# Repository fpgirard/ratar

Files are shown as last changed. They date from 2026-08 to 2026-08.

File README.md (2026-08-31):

Ratar logo

# Ratar

*Rage Against the Alkaline Remote — RF signal capture & replay with an XIAO ESP32-C6 and CC1101*

<br clear="left"/>

Just as [Paul Wieland built his Ratgdo](https://www.nytimes.com/2025/12/04/technology/personaltech/why-on),
my goal was equally simple: an open-source, sub-$10 device to control my Minka-Aire
fans (FCC ID **KUJCE10007**), built from the same kind of open-source
software and commodity parts he used — ESPHome, 3D printing, inexpensive
ESP32 boards with an added CC1101-based RF module.

I also planned to capture my Minka-Aire remotes' RF codes directly, or fall
back to a [Flipper repository of RF codes](https://github.com/search?q=repo%3AZero-Sploit%2FFlipperZero-Subghz-DB+minka&type=code)
if needed.

While Ratar is narrow in scope today, I designed it to support a much
larger idea: a universal, community-supported RF/IR transceiver, where the
hardware (PCBs), software (YAML), and CAD (OpenSCAD) files are shared and
easily extensible to any 300–928MHz remote. (I'm currently adding an IR
LED/receiver to the Ratar HAT.)

---

## Repo layout

It's clean and simple, and should be easy to navigate. Questions or
comments? Please use Issues above to post.

| Path | Contents |
|---|---|
| [`pcb/README.md`](pcb/README.md) | Hardware — component list, CC1101↔XIAO pin assignments, the RF-HAT KiCad project |
| [`src/README.md`](src/README.md) | Software — the ESPHome `cc1101` config, reverse-engineering notes, Signal Bench pointer |
| [`3d/README.md`](3d/README.md) | Enclosure — parametric OpenSCAD design for the printed case |
| `OPL_Kicad_Library/` | Git submodule — Seeed's KiCad footprint/symbol library, used by the RF-HAT PCB |
| `ratar.svg`, `ratar-color.svg` | Project logo |

`OPL_Kicad_Library/` is a git submodule, so clone with:

```sh
git clone --recurse-submodules https://github.com/fpgirard/ratar.git
```

(Already cloned without it? Run `git submodule update --init` to pull it in.)

---

## Future enhancements

See each area's own README for topic-specific roadmap items (IR support and
protocol decoding in [`src/`](src/README.md), the KiCad schematic net-label
cleanup in [`pcb/`](pcb/README.md)).

By design, the house-shaped Ratar logo is drawn from the KiCad copper
traces on the PCB HAT. :)

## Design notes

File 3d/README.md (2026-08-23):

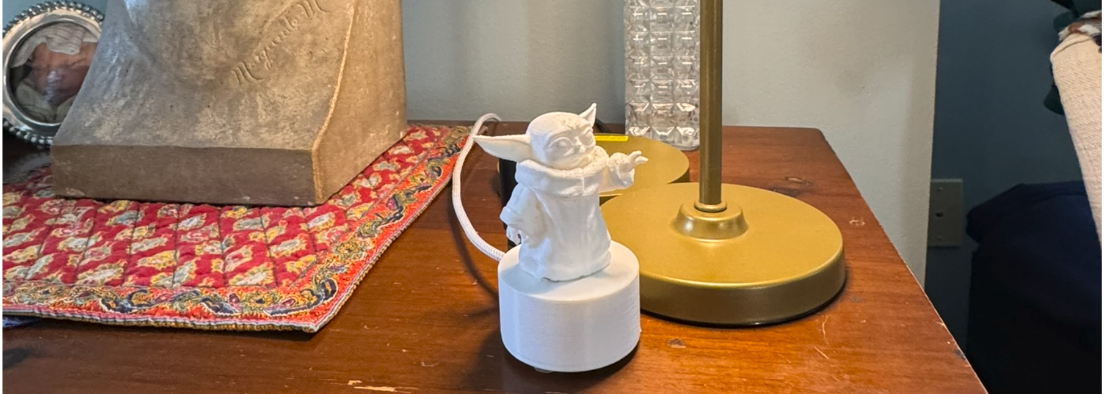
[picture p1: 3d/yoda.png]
3D-printed Grogu figurine, unrelated to Ratar -- just for fun


# Enclosure

*Ratar's printed enclosure: a parametric OpenSCAD (BOSL2) design*

A 50mm-diameter cylindrical two-part enclosure (base + lid) for the RF-HAT
board, sized to hold both the XIAO ESP32-C6 + CC1101 stack and a second,
wider board tier above it. Yoda is optional.

## Design highlights

- **Two-tier cavity**: a board cavity sized to the PCB, with a wider cutout
  starting partway up that continues through the top of the base — room for
  a second, larger board or extra component clearance above the main stack.
- **Antenna and USB-C cutouts**: both the round cable hole and the
  USB-C slot on the outer wall are cut as a small through-bore plus a wider,
  shallow counterbore pocket with a controlled flat shoulder between them —
  the trick that lets a flat connector face sit cleanly on an otherwise
  curved wall.
- **Bolted lid**: two M2 socket-head (Allen) bolts thread into heat-set
  brass inserts in the body, rather than a snap-fit or press-fit-only lid.
- **Fully parametric**: every dimension — board size, wall thickness, hole
  positions/sizes, bolt spacing, standoff heights — is a named variable at
  the top of the `.scad` file. Re-render after changing any of them.

## Print notes

Base and lid both print flat on the bed as oriented in the file (open
side / lid facing up); no supports needed.

## Files

- `ratar.scad` — the parametric source. Requires the
  [BOSL2](https://github.com/BelfrySCAD/BOSL2) OpenSCAD library
  (`include <BOSL2/std.scad>`, `include <BOSL2/screws.scad>`).
- `ratar.stl`.  Exported mesh, ready to slice.

To regenerate the STL after editing the source:

```sh
openscad -o ratar.stl ratar.scad
```

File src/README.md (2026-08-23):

Ratar logo

# Software

*ESPHome firmware for Ratar — RF capture and replay on the CC1101*

There are 2 software components in Ratar: 1. The ESPHome yaml configuration
file necessary to control your RF-based devices.  2. Signal Bench - a prototype
database to help the community collect and share their raw codes.  This resource
will be made available if the community requests it - while realizing that 
existing RF and IR code repositories already exist.   

## ESPHome + the built-in `cc1101` component

The build uses ESPHome's **official `cc1101` component**, added in
ESPHome **2025.12.0**. This was a major simplification partway through the
project — earlier revisions hand-rolled every SPI register write (reset
sequence, frequency registers, modulation config) either via Arduino's
`SPIClass` or, on the ESP-IDF-only C6, via raw bit-banged `gpio_set_level()`
calls. The built-in component eliminates all of that: frequency and
modulation are plain YAML keys, and it integrates directly with ESPHome's
standard `remote_receiver` / `remote_transmitter` components for capture
and replay.

## Complete working configuration

Please review the file `rf-transceiver-sample.yaml` for a working configuration.

## Why 304MHz, not 315MHz

315MHz is the common default assumption for fixed-code fan/garage remotes,
but this specific remote's FCC filing (FCC ID KUJCE10007) documents
**304.0MHz** as its actual operating frequency. Worth checking your own
device's FCC filing rather than assuming a round-number default — the
CC1101's filter bandwidth has some tolerance, but being off by 10MHz+ can
mean the difference between a clean capture and nothing at all.

## Frequency/reverse-engineering notes worth preserving

- Both remotes use a **fixed-code, non-rolling** OOK protocol: an 8-bit
  device/address prefix plus a 4-bit command suffix, with each button
  repeating its code ~6-7 times per press (~11,800µs gap between repeats).
- The two remotes have distinct address prefixes (`00000000` and
  `00000001`), confirming the address bits are what let two remotes/fans
  coexist without cross-triggering each other.
- One remote's "reverse" function was concluded to not exist via RF at
  all: applying the working remote's reverse command-suffix to the other
  remote's address prefix predicts a code that's identical to that
  remote's existing High Speed command — a genuine collision, not a
  capture failure. That fan's direction control is very likely a
  mechanical switch in the receiver canopy instead.
- Long-press behavior (dimming) on this remote family is **receiver-side**:
  holding a light button just re-sends the identical toggle code
  continuously: there's no distinct "dim" RF command. Simulating
  press-and-hold dimming in ESPHome means looping `transmit_raw` on a
  timer until told to stop, not sending a different code.

## Directory contents

- `rf-transceiver-sample.yaml` — the ESPHome CC1101 RF capture/replay
  config, with placeholder secrets and API key. Your own `rf-transceiver.yaml`
  (real device name, API key, captured codes) is gitignored — copy the
  sample to that filename and fill in your own values.
- `fix_xiao_footprints.py` — utility script for XIAO KiCad footprint fixes.

## Related: Signal Bench

**Signal Bench** is a separate, self-hosted FastAPI web app (not vendored in
this repo) built alongside this project for cataloging RF/IR codes as a
community resource — paste raw ESPHome `remote_receiver` debug output and it
parses, renders, and stores the code, seeded with the real captures from
this project. See that app's own README for setup.

## Future enhancements

- **IR transmitter and receiver support on the same board.** The CC1101
  handles sub-GHz RF; a standard IR LED (TX) and demodulating IR receiver
  module (RX, e.g. a VS1838B) would let one device handle both RF and IR
  devices in a home, using the same `remote_transmitter`/`remote_receiver`
  pattern already proven here — ESPHome's `remote_receiver`/
  `remote_transmitter` components are protocol-agnostic and already used
  for IR in most ESPHome IR-blaster builds.
- **Protocol-level decoding**, not just raw replay — recognizing known
  encodings (NEC, RC5, etc. for IR; common fixed-code and rolling-code
  families for RF) so Signal Bench can show a decoded address/command
  breakdown automatically instead of just the raw pulse train.
- **Frequency sweep / auto-detect** for captures, rather than requiring the
  operating frequency to be known ahead of time (useful for devices without
  an easily found FCC filing).
- **Moderation/verification workflow** for Signal Bench submissions, so a
  growing public catalog stays trustworthy as more contributors add codes.

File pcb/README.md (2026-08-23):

Ratar logo

# Hardware

*RF-HAT — CC1101 ↔ XIAO ESP32-C6 carrier board*

Ratar's hardware has four parts: the XIAO ESP32-C6, a CC1101 sub-GHz
transceiver module, Ratar's custom carrier PCB (the "RF-HAT"), and an SMA
antenna.

| Component | Role |
|---|---|
| **Seeed XIAO ESP32-C6** | Main microcontroller. Chosen over the ESP32-S3 specifically for its **built-in ceramic antenna** — avoids needing an external antenna for the C6's own WiFi/BLE radio. Requires the **ESP-IDF** framework in ESPHome (Arduino isn't supported on this chip). |
| **CC1101 sub-GHz transceiver module** (8-pin breakout, SMA antenna connector) | The actual RF transceiver. Handles 300–928MHz, ASK/OOK and other modulations. Controlled entirely over SPI. |
| **Custom KiCad PCB ("RF-HAT")** | Connects the CC1101 module's 8-pin header to the XIAO C6's pins — designed with copper traces in the shape of a house (see the logo), and verified against the pinout table below before fabrication. |
| **Right-angled SMA antenna** | Rated for the ~300MHz range Minka-Aire remotes use — not all "SMA-compatible" antennas are tuned correctly for this band. An elbow connector is worth using if the antenna would otherwise sit close to and in-line with a noise source like a USB-C cable/connector, since it moves the radiating element further away and off-axis. |

## Pin assignments — CC1101 ↔ XIAO ESP32-C6 (final)

| CC1101 Pin # | Signal | XIAO Pin | GPIO | Notes |
|---|---|---|---|---|
| 1 | GND | GND | - | |
| 2 | VCC | 3V3 | - | 1.8-3.6V only - never 5V |
| 3 | GDO0 | D2 | GPIO2  | Wired to `remote_transmitter` (TX path) |
| 4 | CSN | D3 | GPIO21 | SPI chip select |
| 5 | SCK | D8 | GPIO19 | SPI clock |
| 6 | MOSI | D10 | GPIO18 | SPI data in |
| 7 | MISO / GDO1 | D9 | GPIO20 | SPI data out (dual-purpose pin) |
| 8 | GDO2 | D1 | GPIO1  | Wired to `remote_receiver` (RX/capture path) |

All connections use clean, non-strapping GPIOs on the C6.

**A note on the KiCad schematic**: when Ratar's RF-HAT board was designed, the CC1101 header (`J1`) was wired as a generic 8-pin connector with no net labels. If you're referencing or modifying the KiCad source, verify the physical pin-to-signal mapping against the table above (and against how the CC1101 module actually plugs into the header) before trusting the schematic alone — run KiCad's ERC and pull the netlist to catch any wiring mismatches (a GND/VCC short was caught this way during this build) rather than relying on manual trace-reading.

## Manufacturing

If you're using PCBWay, `RF-HAT.kicad_pcb.zip` can be uploaded directly —
the board is small enough (comfortably under 100×100mm) that ordering 5 or
10 copies costs the same $5 prototype price.

## Directory contents

- `RF-HAT/` — the KiCad project: schematic, PCB layout, and fab-ready
  gerbers/drill files.
- `OPL_Kicad_Library/` (at the repo root, git submodule) — Seeed's KiCad
  footprint/symbol library, used for the XIAO and other Seeed parts on this
  board.

## Future enhancements

- **Resolve the KiCad schematic labeling gap** — add proper net labels to
  the RF-HAT schematic so future revisions (or anyone else building from
  the design files) don't have to manually trace wire coordinates to
  verify pin assignments.

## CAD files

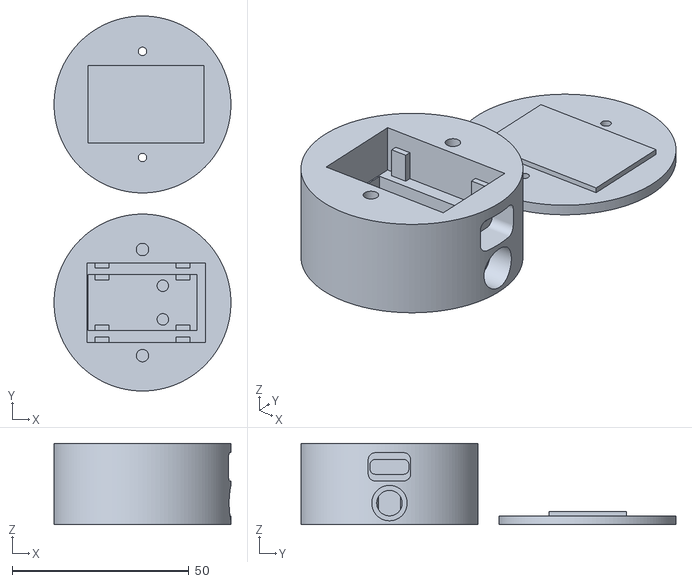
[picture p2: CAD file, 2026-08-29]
3d/ratar.stl
50.0 x 106.0 x 23.0

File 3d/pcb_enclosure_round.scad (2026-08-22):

// ============================================================
//  PCB Enclosure (Round) — Parametric OpenSCAD Design (BOSL2)
//  Variant of pcb_enclosure.scad with a fully cylindrical 50mm-
//  diameter outer shell instead of a rectangular one. The internal
//  cavity (and its standoffs) is centered in the shell. The cable
//  hole is a stepped bore: a small through-hole reaches the cavity,
//  opening into a wider, shallow counterbore pocket cut into the
//  curved outer surface -- that pocket's flat bottom leaves a
//  controlled hole_wall_thickness shoulder for the cable/connector.
//  Above upper_cavity_start_height the cavity steps out to a wider
//  footprint (upper_cavity_length x upper_cavity_width) that runs up
//  through the top of the base -- that wider opening is also what the
//  lid's lip is now sized to. A USB-C slot sits in the same +X wall as
//  the circular hole, usb_c_offset_z above that hole's center.
//  The body is box_height tall overall. The lid is held on by two M2
//  countersunk bolts (centered in X, lid_bolt_spacing_y apart in Y)
//  threading into matching heat-set insert holes blind-drilled into
//  the body's top rim.
//  Units: mm
// ============================================================

include <BOSL2/std.scad>
include <BOSL2/screws.scad>

// --- PCB assembly bounding box (board + all components) ---
pcb_length       = 30; // Board length (X)
pcb_width        = 15; // Board width (Y) -- the two end walls face this dimension
pcb_stack_height = 15; // Overall height of the board assembly (PCB thickness plus
                        // the tallest component on either face), resting on the shoulders

// --- Fit clearances ---
side_clearance = 0.4; // Per-side X/Y clearance between the board edge and the
                       // cavity wall, so the board drops in without binding
                       // (top_clearance, the headroom above the tallest
                       // component, is derived below from box_height --
                       // it MUST stay greater than lip_engage_depth, or the
                       // lid's alignment lip will crush tall components)

// --- Shell ---
outer_dia       = 50;  // Outer diameter of the cylindrical shell
box_height      = 23;  // Overall height of the body, floor to rim
floor_thickness = 2;   // Floor thickness under the support shoulders
lid_thickness   = 2.5; // Lid panel thickness

// --- Cavity placement ---
cavity_offset_x = 0; // How far the internal cavity (and everything inside it)
                      // is shifted off-center, towards the +X cable-hole side.
                      // 0 = centered in the round shell.

// --- PCB support standoffs (2 per 30mm-long side wall, 4 total) ---
pcb_support_height = 4;   // Height above the floor's top surface where the PCB
                           // rests -- also the reference height for the side hole
standoff_length = 4;      // Standoff size along X (the wall's running direction)
standoff_depth  = 1.5;    // How far each standoff protrudes inward from its side
                           // wall (Y)
standoff_inset  = 2;      // Gap between each end wall's inner face and the near
                           // edge of the nearest standoff, along X

// --- Upper standoffs (4, for the upper cutout's board) -- same X offsets
// and X/Y footprint as the standoffs above, just taller and set against the
// upper cutout's (wider) side walls instead ---
upper_standoff_height = 5.25; // Height above upper_cavity_z where these rest

// --- Round center standoffs (2, likely for screw-mounting the PCB) ---
round_standoff_dia      = 3.25; // Outer diameter of each round standoff
round_standoff_spacing_y = 9.5; // Center-to-center spacing between the two, along Y
round_standoff_offset_x  = 5.75; // Offset from center (X=0) towards the hole wall (+X)
round_standoff_height    = pcb_support_height + 2; // 2mm taller than the corner
                              // standoffs, so this pair's top surface sits 2mm higher

// --- Side hole (cable/connector cutout, +X side) ---
side_hole_dia              = 7.2;  // Through-hole diameter, cavity to counterbore
side_hole_bottom_clearance = 0.5;  // Gap between the hole's bottom edge and the
                                   // interior floor
hole_wall_thickness        = 3;    // Thickness of the flat shoulder left at the
                                   // counterbore's bottom, for the cable hole
counterbore_dia            = 10;   // Diameter of the shallow flat-bottomed pocket
                                   // cut into the curved outer surface

// --- Upper cutout (second, wider cavity step above the board cavity) ---
upper_cavity_length     = 33.5; // X extent of the upper cutout
upper_cavity_width      = 22.5; // Y extent of the upper cutout
upper_cavity_start_height = 10; // Height above the interior floor where the
                                 // cutout widens -- it continues up through
                                 // the top of the base from there
upper_cavity_offset_x   = 1; // Shifted 1mm in +X from the shell's center --
                                 // the lid lip follows this too

// --- USB-C cutout (+X wall, same side as the circular hole) ---
usb_c_width    = 9;   // Slot width, along Y -- reaches the cavity for the PCB connector
usb_c_height   = 3.2; // Slot height, along Z
usb_c_corner_r = 1.5; // Corner rounding -- close to usb_c_height/2 for a stadium slot
usb_c_offset_z = 8;   // How far above the circular hole's center the slot is centered
usb_wall_thickness = 0.5; // Thickness of the flat shoulder left between the cavity
                           // and the housing pocket's bottom, for the USB-C slot --
                           // same stepped-bore idea as hole_wall_thickness above

// USB-C cable housing pocket: a shallow flat-bottomed recess in the curved
// outer surface, concentric with the slot above, sized to clear a cable
// plug housing -- doesn't reach the cavity, just the housing's flare
usb_pocket_width    = 10;  // Pocket width, along Y (cable housing width)
usb_pocket_height   = 7;   // Pocket height, along Z (cable housing height)
usb_pocket_corner_r = 2;   // Rounded corners, not a full stadium

// --- Lid retention lip ---
lip_engage_depth   = 1;   // How far the lid's lip drops down inside the box mouth
lip_side_clearance = 0.3; // Per-side clearance so the lip presses in without binding

// --- Lid fasteners: M2 socket-head (Allen) bolts into heat-set inserts in
// the body, modeled with BOSL2's screws.scad (screw_hole()) so the shank
// clearance and head size come from real ISO M2 spec data instead of
// hand-picked numbers. Centered in X, spaced lid_bolt_spacing_y apart in Y.
// Sized for M2x8 -- a shallow spot-face counterbore seats the socket head
// squarely; unlike a countersunk head, a socket head normally sits proud
// rather than flush, so this stays shallow (rather than the library's
// default full-head-height counterbore) to keep the lid from getting
// paper-thin underneath it ---
lid_bolt_spacing_y = 30;  // Center-to-center spacing between the two bolts (Y)
lid_bolt_length    = 8;   // M2x8
m2_counterbore_depth = 0.7; // Spot-face depth -- head sits proud above this,
                             // well short of the socket head's ~2mm height

m2_insert_dia   = 3.5; // Heat-set insert outer diameter (M2 brass/copper insert)
m2_insert_depth = 9;   // Blind hole depth in the body for the insert --
                        // deep enough that an M2x8 bolt doesn't bottom out

// --- Base floor label: "RATAR" engraved (inverted, i.e. recessed rather
// than raised) into the interior floor -- hidden under the board once
// assembled. It reads the same forwards and backwards; as a nod to that,
// the last R is mirrored vertically and recessed 1mm deeper than the rest ---
label_text        = "RATAR"; // everything but the mirrored last letter
label_last_letter = "R";
label_font_size   = 3.5;
label_gap         = 1;   // gap between "RATA" and the mirrored R, along X
label_x           = -3;  // floor position, clear of both standoff types
label_depth       = 0.3; // engrave depth for the normal letters
label_mirror_offset = 1; // extra depth for the mirrored R, per the request

// --- Derived dimensions ---
internal_length = pcb_length + 2 * side_clearance;
internal_width  = pcb_width + 2 * side_clearance;
internal_height = box_height - floor_thickness;
top_clearance   = internal_height - pcb_support_height - pcb_stack_height;

outer_radius = outer_dia / 2;
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

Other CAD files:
3d/ratar.scad

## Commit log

2026-08-22 Initial commit: clean up tree, submodule OPL_Kicad_Library, split README
    - Remove macOS .DS_Store/._* cruft and KiCad's auto-history/.lck files;
    cover them (plus the vendored submodule exception) in .gitignore
    - Convert OPL_Kicad_Library from a polluted in-place checkout to a real
    git submodule, pinned to the same commit it was already at
    - Split the 299-line root README into focused docs: pcb/README.md
    (hardware), src/README.md (software), 3d/README.md (new -- enclosure,
    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
    [RF-HAT-B_Cu.gbr, RF-HAT-B_Mask.gbr, RF-HAT-B_Paste.gbr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]
2026-08-23 Rebrand 3D source, refresh README content, gitignore local-only files
    - Restore 3d/ratar.scad (was accidentally saved as SVG data instead of
    the OpenSCAD source) from the known-good copy, renamed from
    pcb_enclosure_round.scad/.stl to ratar.scad/.stl
    - Add project logo to root README, personalize intro
    - Fix pcb/README.md tables (stray empty rows, mismatched separator
    column count, em-dash alignment) and drop stale manufacturing-report
    reference
    - Swap src/rf-transceiver.yaml for a checked-in sanitized
    rf-transceiver-sample.yaml; the real per-device config (and a local
    `notes` scratch file) are now gitignored
    - Update src/README.md directory listing to match
    [ratar.scad, ratar.stl]
2026-08-23 Establish Ratar as the project/device name, tighten README wording
    - Root title is now "Ratar", subtitled with the full expansion (Rage
    Against the Alkaline Remote) instead of leading with the phrase
    - Fix grammar/typos (comma splices, "extensable", double spaces,
    "Please uses Issues") and standardize logo alt text across all four
    READMEs
    - pcb/: reworded component intro, fixed "shape of a home" -> "house",
    tightened the PCBWay pricing note, de-duplicated manufacturing detail
    - src/: tightened the Signal Bench reference sentence
    - 3d/: fixed alt text that mislabeled the Grogu photo as the logo,
    consistent subtitle style, removed stray code-block indentation
2026-08-23 Add submodule clone note, point src/ at the sample config, small edits
    - README: note that OPL_Kicad_Library is a submodule and needs
    --recurse-submodules (or a follow-up submodule update --init)
    - src/README.md: replace the embedded YAML block with a pointer to
    rf-transceiver-sample.yaml, add a 2-component software overview;
    fix a dangling "config above" reference left after removing the
    inline block
    - 3d/README.md: minor wording touch-ups
2026-08-23 Tweak intro wording: ESP32 (not ESP32-C6 specifically) with a CC1101 module
2026-08-29 Raise upper standoffs and USB-C cutout, widen USB-C, flip lid for print
    - upper_standoff_height +1.5mm for taller PCB headers
    - USB-C slot/pocket +2mm wide (Y), +1mm tall (Z)
    - USB-C cutout moved +2.25mm up (Z), clearing its earlier overlap with
    the round cable hole's counterbore
    - Lid is now pre-flipped in the print layout (lip-up, flat face down)
    so no manual slicer rotation is needed
    - hole_wall_thickness settled at 3.25 after a couple of iterations
    - lip_engage_depth 1 -> 1.25, m2_counterbore_depth 0.7 -> 1
    [ratar.scad, ratar.stl]
